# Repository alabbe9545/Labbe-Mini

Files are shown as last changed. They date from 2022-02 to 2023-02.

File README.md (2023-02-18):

# Labbe-Mini

This is a project that helped me learn how to make keyboards, this might also help anyone thinking of making their own PCB.

Before opening it on Kicad download the following libraries and place them in the root folder inside ExtLibraries folder (create the folder):
* https://github.com/KiCad/Housings_QFP.pretty (should be named Housings_QFP.pretty)
* https://github.com/tmk/keyboard_parts.pretty (should be named keyboard_parts.pretty)
* https://github.com/tmk/kicad_lib_tmk (should be named kicad_lib_tmk-master)
* https://github.com/sszczep/kicad-libraries (should be named kicad-libraries-master)

Some nice pictures of the keyboard

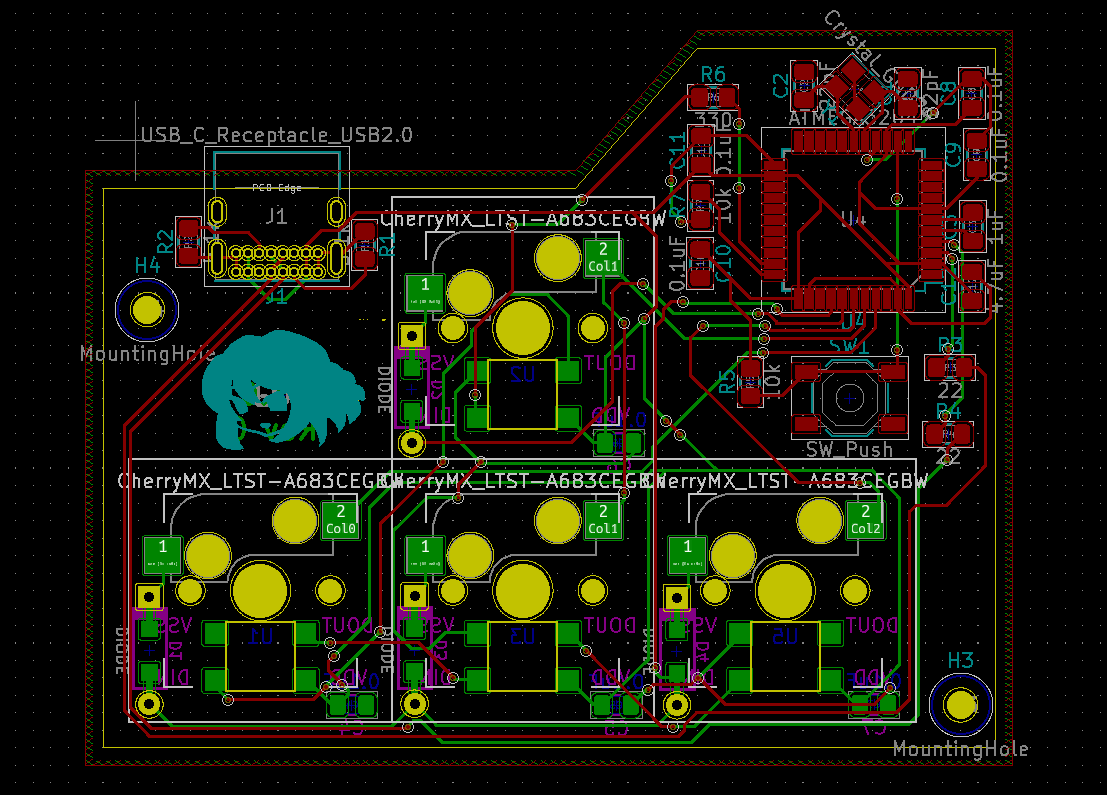
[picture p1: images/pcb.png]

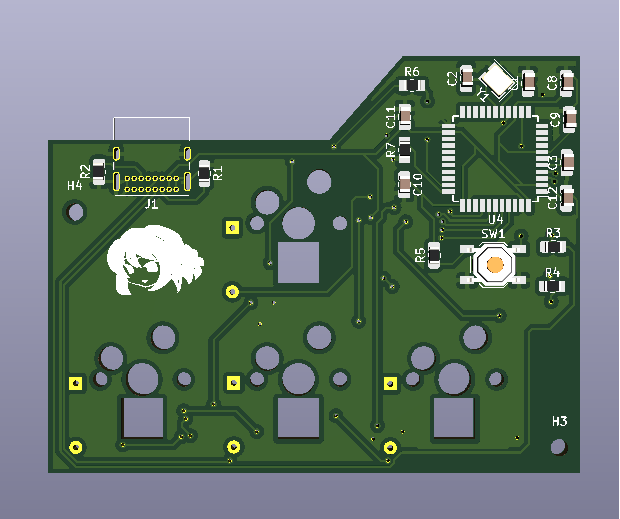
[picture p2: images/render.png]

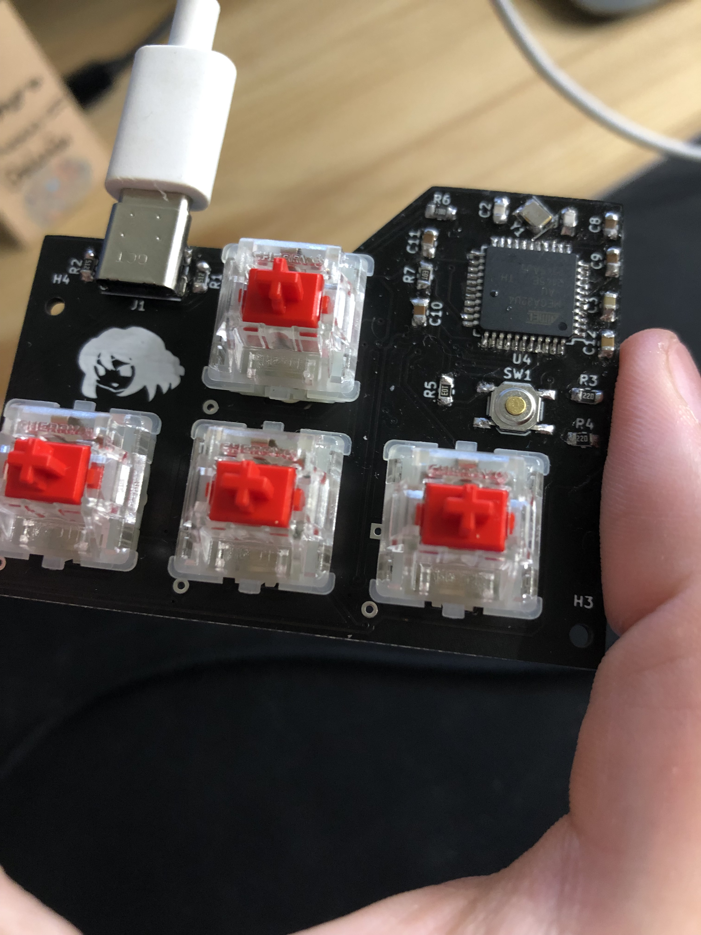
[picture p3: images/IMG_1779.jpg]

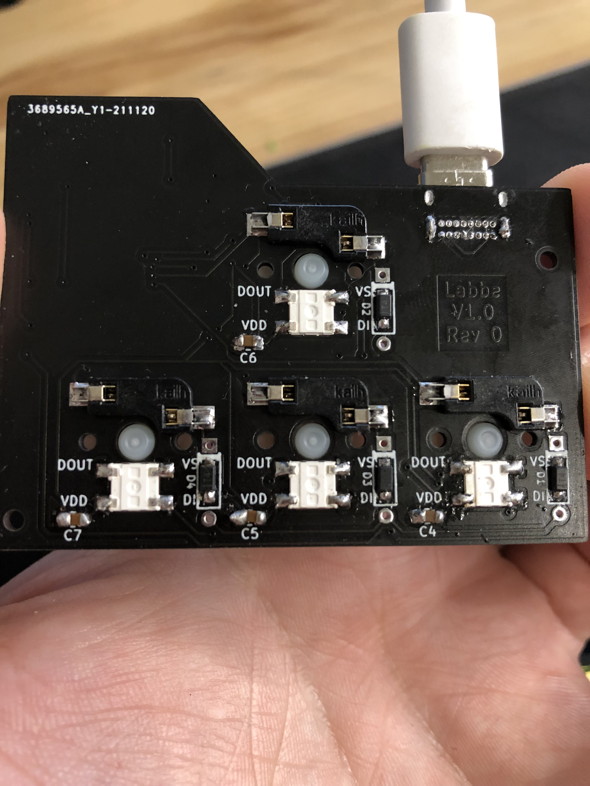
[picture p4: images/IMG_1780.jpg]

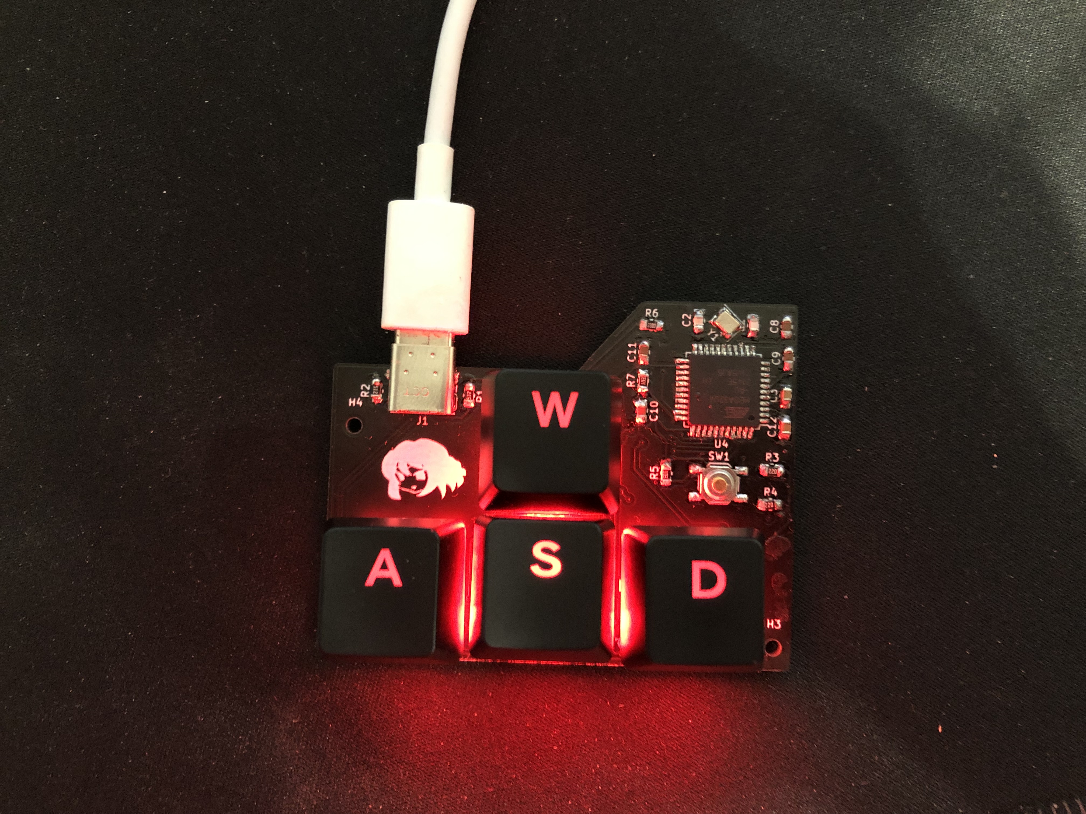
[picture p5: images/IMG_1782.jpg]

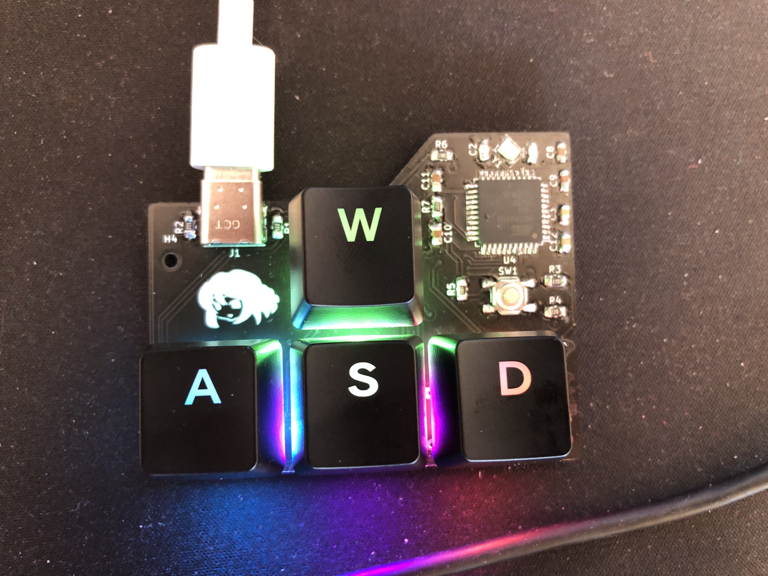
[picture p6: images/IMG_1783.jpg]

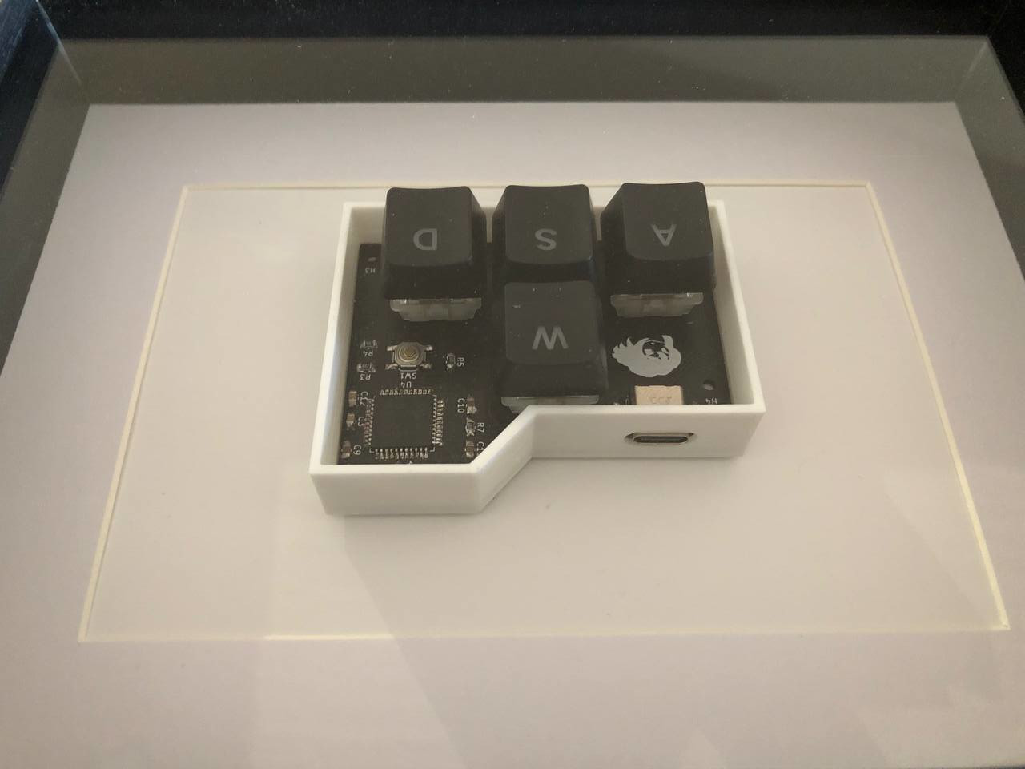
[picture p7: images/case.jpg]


Pieces needed
* 4 x WS2812B 5050 RGB LEDs (https://aliexpress.com/item/1005002653014067.html?gatewayAdapt=glo2deu&spm=a2g0o.9042311.0.0.55134c4dMfKc13)
* 4 x Kaihl Hotswap sockets (https://aliexpress.com/item/32951252318.html?gatewayAdapt=glo2deu&spm=a2g0o.9042311.0.0.55134c4dMfKc13)
* 4 x Compatible mechanical switches (Cherry, Kaihl, etc)
* 1 x Atmega32U4 (https://www.digikey.de/de/products/detail/microchip-technology/ATMEGA32U4-AUR/2238241)
* 4 x Diodes (https://www.digikey.de/de/products/detail/taiwan-semiconductor-corporation/1N4148W-G-RHG/7374103)
* 2 x 22 Ohm Resistors (https://www.digikey.de/de/products/detail/stackpole-electronics-inc/RMCF0805JT22R0/1757897)
* 2 x 10k Ohm Resistors (https://www.digikey.de/de/products/detail/stackpole-electronics-inc/RMCF0805JT10K0/1757762)
* 1 x 330 Ohm Resistor (https://www.digikey.de/de/products/detail/stackpole-electronics-inc/RMCF0805FT330R/1760484)
* 2 x 5.1k Ohm Resistor (https://www.digikey.de/de/products/detail/stackpole-electronics-inc/RMCF0805JT5K10/1757930)
* 8 x 0.1uF Capacitors (https://www.digikey.de/de/products/detail/yageo/CC0805ZRY5V9BB104/2103099)
* 1 x 1uF Capacitor (https://www.digikey.de/de/products/detail/yageo/CC0805KKX7R7BB105/2103103)
* 1 x Button (https://www.digikey.de/de/products/detail/e-switch/TL3342F160QG-TR/379003)
* 2 x 22pF Capacitors (https://www.digikey.de/de/products/detail/kemet/C0805C220J5GAC7800/411112)
* 1 x 4.7uF Capacitor (https://www.digikey.de/de/products/detail/murata-electronics/GRM219R61E475KA73D/4905426)
* 1 x 16MHZ Quartz Crystal (https://www.digikey.de/de/products/detail/ecs-inc/ECS-160-18-33-AEN-TR/8023240)
* 1 x USB-C - USB2 Receptacle (https://www.digikey.de/de/products/detail/gct/USB4085-GF-A/9859662)

Thanks to:
* ai03-2725, to be able to fit the WS2812B 5050 RGB LEDs i modified the footprints of https://github.com/ai03-2725/MX_Alps_Hybrid
* The creator of the nice silkscreen image, euphoria (https://twitter.com/3uf0ria) (https://www.pixiv.net/en/users/17700641).
* QMK Firmware ( https://github.com/qmk/qmk_firmware/tree/master/keyboards/labbe/labbeminiv1 ).

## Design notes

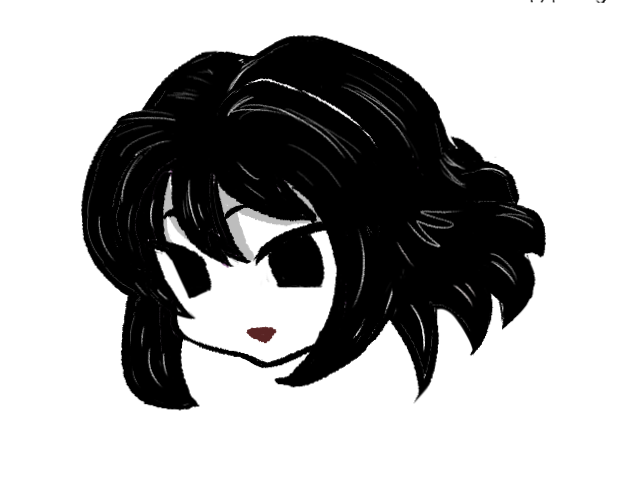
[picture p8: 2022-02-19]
silk.png

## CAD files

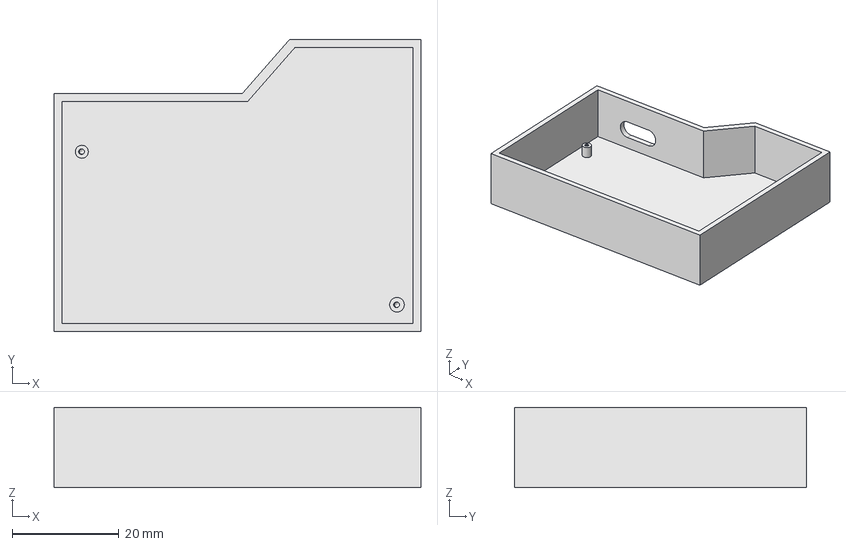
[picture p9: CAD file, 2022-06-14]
case/case.FCStd
68.8 x 54.8 x 15.0 mm

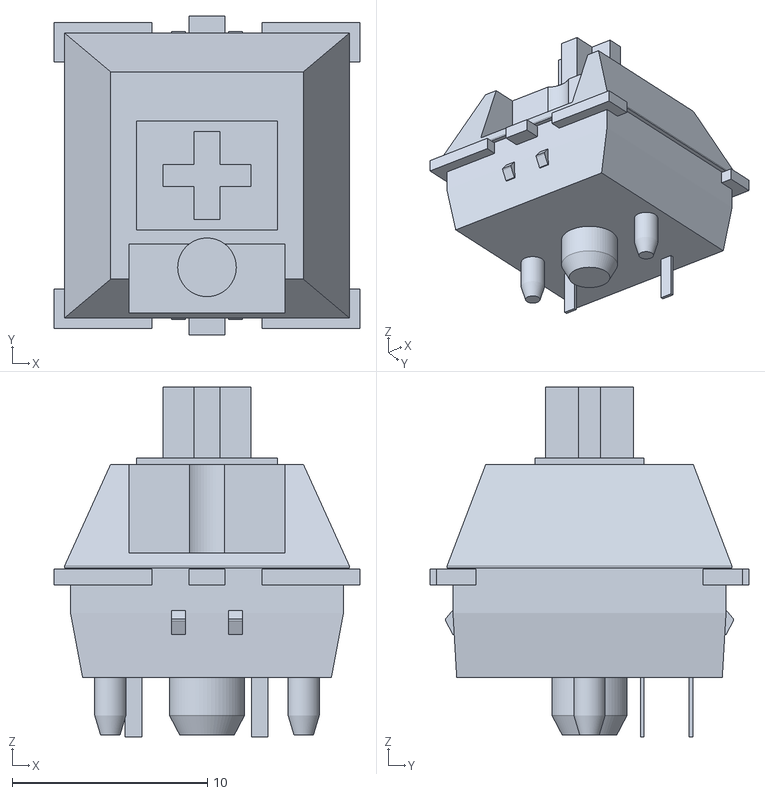
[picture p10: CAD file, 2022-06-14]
case/models/switch_mx.stl
15.6 x 16.3 x 17.9

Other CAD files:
case/case.stl

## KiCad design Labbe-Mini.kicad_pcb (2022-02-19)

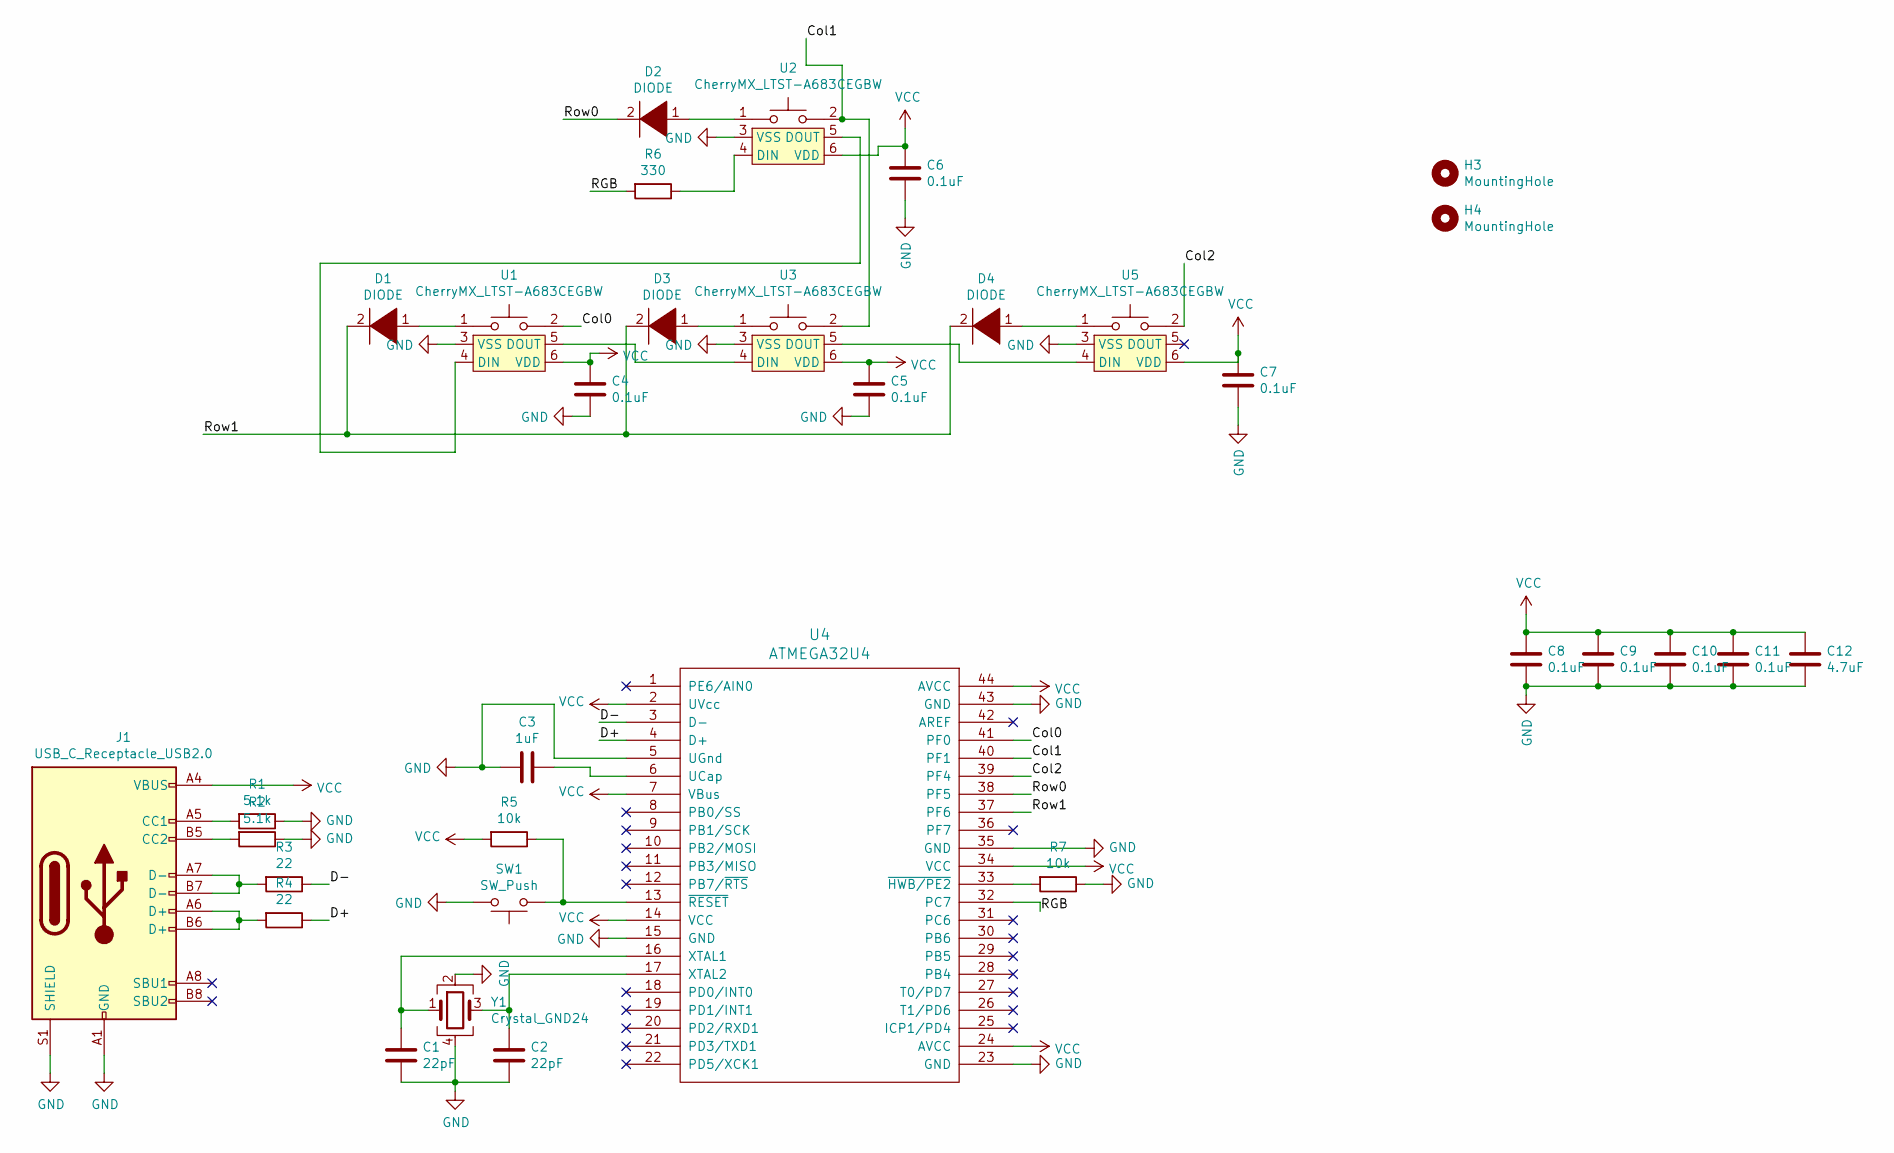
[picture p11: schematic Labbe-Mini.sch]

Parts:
C1, C2: 22pF; C_0805_2012Metric_Pad1.18x1.45mm_HandSolder
C3: 1uF; C_0805_2012Metric_Pad1.18x1.45mm_HandSolder
C4, C5, C6, C7, C8, C9, C10, C11: 0.1uF; C_0805_2012Metric_Pad1.18x1.45mm_HandSolder
C12: 4.7uF; C_0805_2012Metric_Pad1.18x1.45mm_HandSolder
D1, D2, D3, D4: DIODE; D_SOD123_axial
H3, H4: MountingHole; MountingHole_2.1mm
J1: USB_C_Receptacle_USB2.0; USB_C_Receptacle_GCT_USB4085
R1, R2: 5.1k; R_0805_2012Metric_Pad1.20x1.40mm_HandSolder
R3, R4: 22; R_0805_2012Metric_Pad1.20x1.40mm_HandSolder
R5, R7: 10k; R_0805_2012Metric_Pad1.20x1.40mm_HandSolder
R6: 330; R_0805_2012Metric_Pad1.20x1.40mm_HandSolder
SW1: SW_Push; SW_SPST_TL3342
U1, U2, U3, U5: CherryMX_LTST-A683CEGBW; MXOnly-1U-Hotswap
U4: ATMEGA32U4; TQFP-44_10x10mm_Pitch0.8mm
Y1: Crystal_GND24; Crystal_SMD_3225-4Pin_3.2x2.5mm

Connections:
/Col0: U1.2, U4.41 (PF0)
/Col1: U2.2, U3.2, U4.40 (PF1)
/Col2: U4.39 (PF4), U5.2
/D+: R4.1, U4.4 (D+)
/D-: R3.1, U4.3 (D-)
/RGB: R6.2, U4.32 (PC7)
/Row0: D2.2 (A), U4.38 (PF5)
/Row1: D1.2 (A), D3.2 (A), D4.2 (A), U4.37 (PF6)
GND: C1.2, C2.2, C3.1, C4.2, C5.2, C6.2, C7.2, C8.2, C9.2, C10.2, C11.2, C12.2, J1.A1 (GND), J1.A12 (GND), J1.B1 (GND), J1.B12 (GND), J1.S1 (SHIELD), R1.1, R2.1, R7.1, SW1.2, U1.3 (VSS), U2.3 (VSS), U3.3 (VSS), U4.5 (UGnd), U4.15 (GND), U4.23 (GND), U4.35 (GND), U4.43 (GND), U5.3 (VSS), Y1.2, Y1.4
unnamed: C1.1, U4.16 (XTAL1), Y1.1
unnamed: C2.1, U4.17 (XTAL2), Y1.3
unnamed: C3.2, U4.6 (UCap)
unnamed: D1.1 (K), U1.1
unnamed: D2.1 (K), U2.1
unnamed: D3.1 (K), U3.1
unnamed: D4.1 (K), U5.1
unnamed: J1.A5 (CC1), R1.2
unnamed: J1.A6 (D+), J1.B6 (D+), R4.2
unnamed: J1.A7 (D-), J1.B7 (D-), R3.2
unnamed: J1.B5 (CC2), R2.2
unnamed: R5.1, SW1.1, U4.13 (~RESET)
unnamed: R6.1, U2.4 (DIN)
unnamed: R7.2, U4.33 (~HWB/PE2)
unnamed: U1.4 (DIN), U2.5 (DOUT)
unnamed: U1.5 (DOUT), U3.4 (DIN)
unnamed: U3.5 (DOUT), U5.4 (DIN)
VCC: C4.1, C5.1, C6.1, C7.1, C8.1, C9.1, C10.1, C11.1, C12.1, J1.A4 (VBUS), J1.A9 (VBUS), J1.B4 (VBUS), J1.B9 (VBUS), R5.2, U1.6 (VDD), U2.6 (VDD), U3.6 (VDD), U4.2 (UVcc), U4.7 (VBus), U4.14 (VCC), U4.24 (AVCC), U4.34 (VCC), U4.44 (AVCC), U5.6 (VDD)

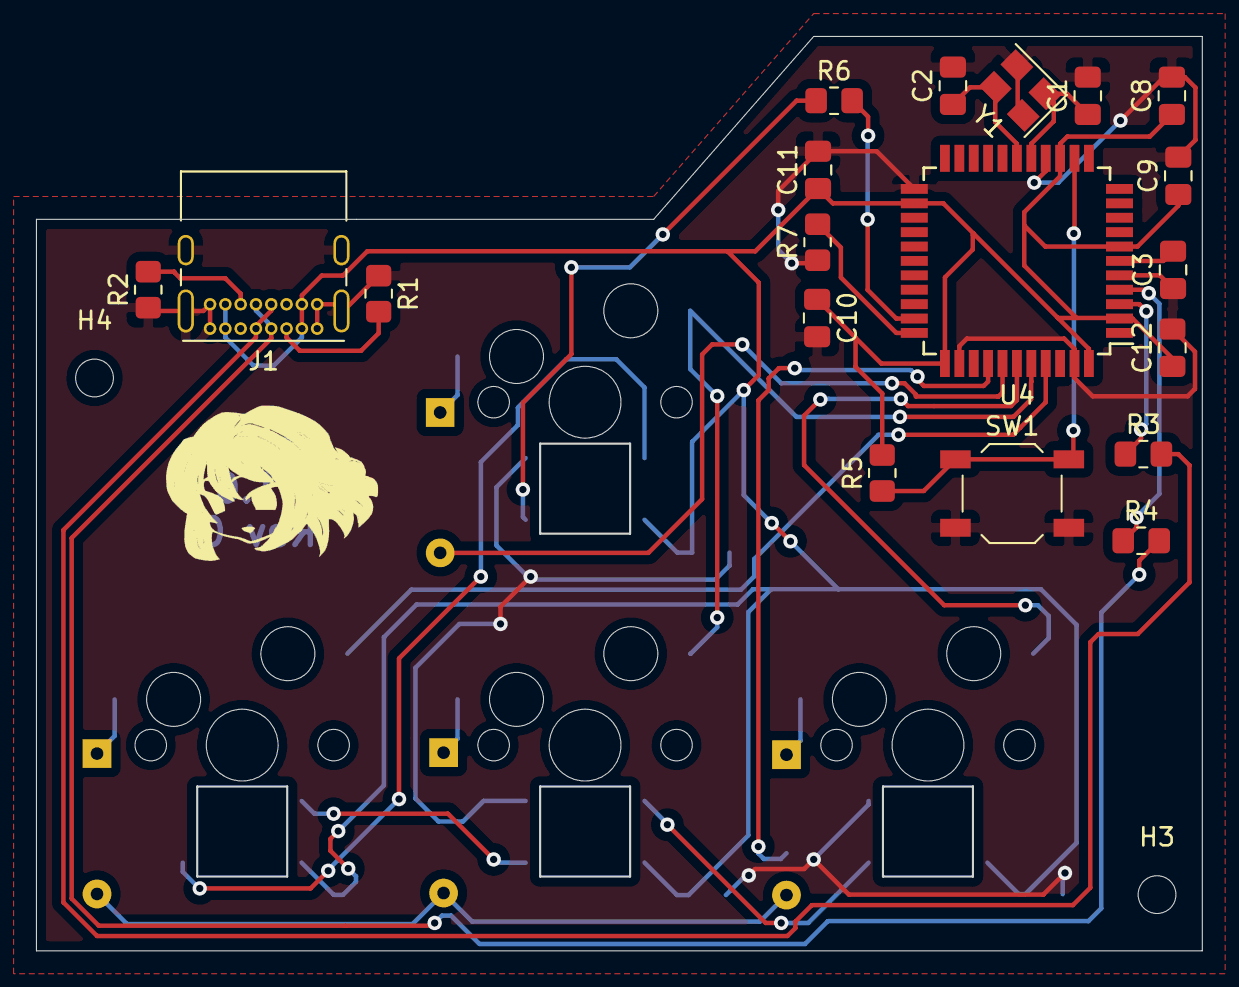
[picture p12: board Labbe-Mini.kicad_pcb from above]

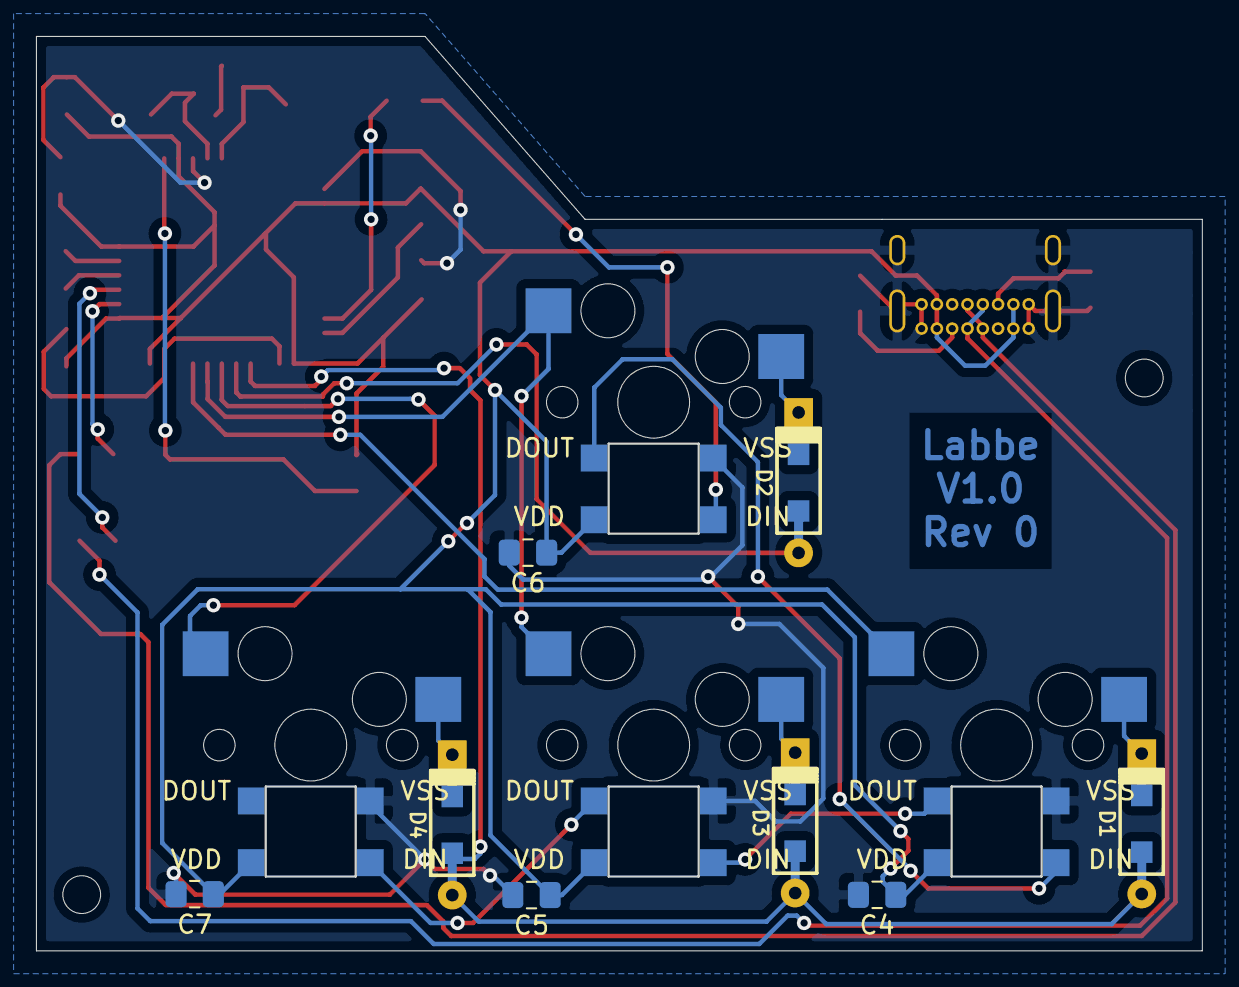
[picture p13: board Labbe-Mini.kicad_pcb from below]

Board: 2 copper layers, 64.8 x 50.8 mm, 33 parts (8 on the bottom side), 27 nets.

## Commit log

2022-02-19 Main - Added images of the PCB
2022-06-14 Adding keyboard case
    [case.FCStd, case.stl, switch_mx.stl]
2022-06-14 Added case pic
